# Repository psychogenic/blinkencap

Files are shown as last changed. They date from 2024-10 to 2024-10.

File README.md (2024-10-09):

# blinkencap

Blinkencap SAO for hackaday supercon badges

This is a simple badge add-on that uses the massive overkill of an ASIC to blink LEDs.

It was inspired by Matt's famous hat:
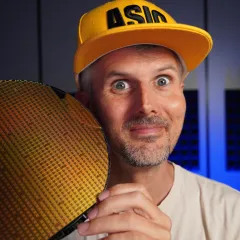
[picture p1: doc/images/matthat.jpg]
Matt and hat


so it looks like

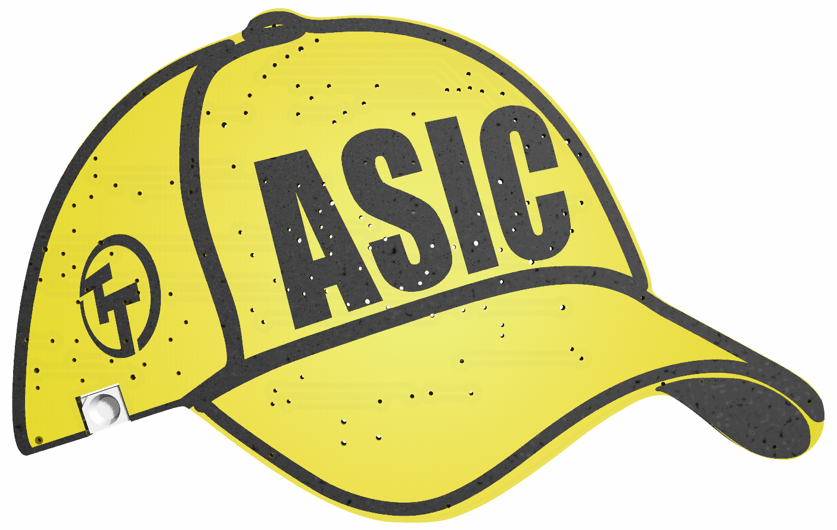
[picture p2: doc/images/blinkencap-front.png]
board front


and gives you a few interesting ways to blink a LED.  All the circuitry is hidden in the back
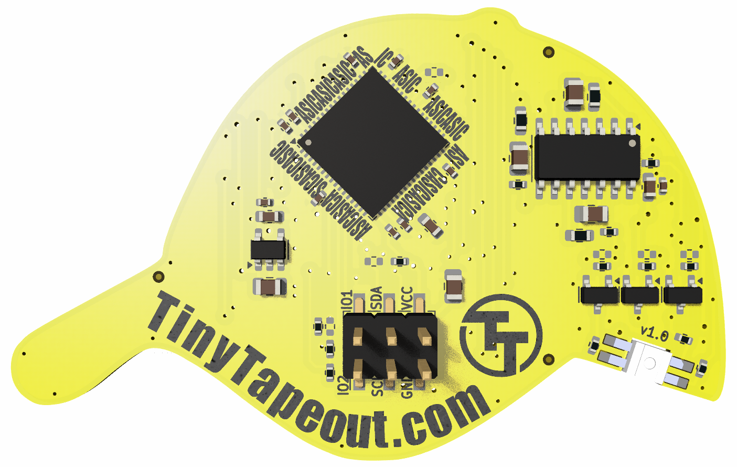
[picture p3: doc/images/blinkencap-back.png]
board components


It is my entry to the [supercon 8 add-on contest](https://hackaday.io/contest/197237-supercon-8-add-on-contest).

It has a project page on [hackaday.io](https://hackaday.io/project/198371-blinkencap), and the circuit can be opened in KiCad or [found in the docs here](https://raw.githubusercontent.com/psychogenic/blinkencap/main/doc/blinkencap-schematic.pdf), but the preview is

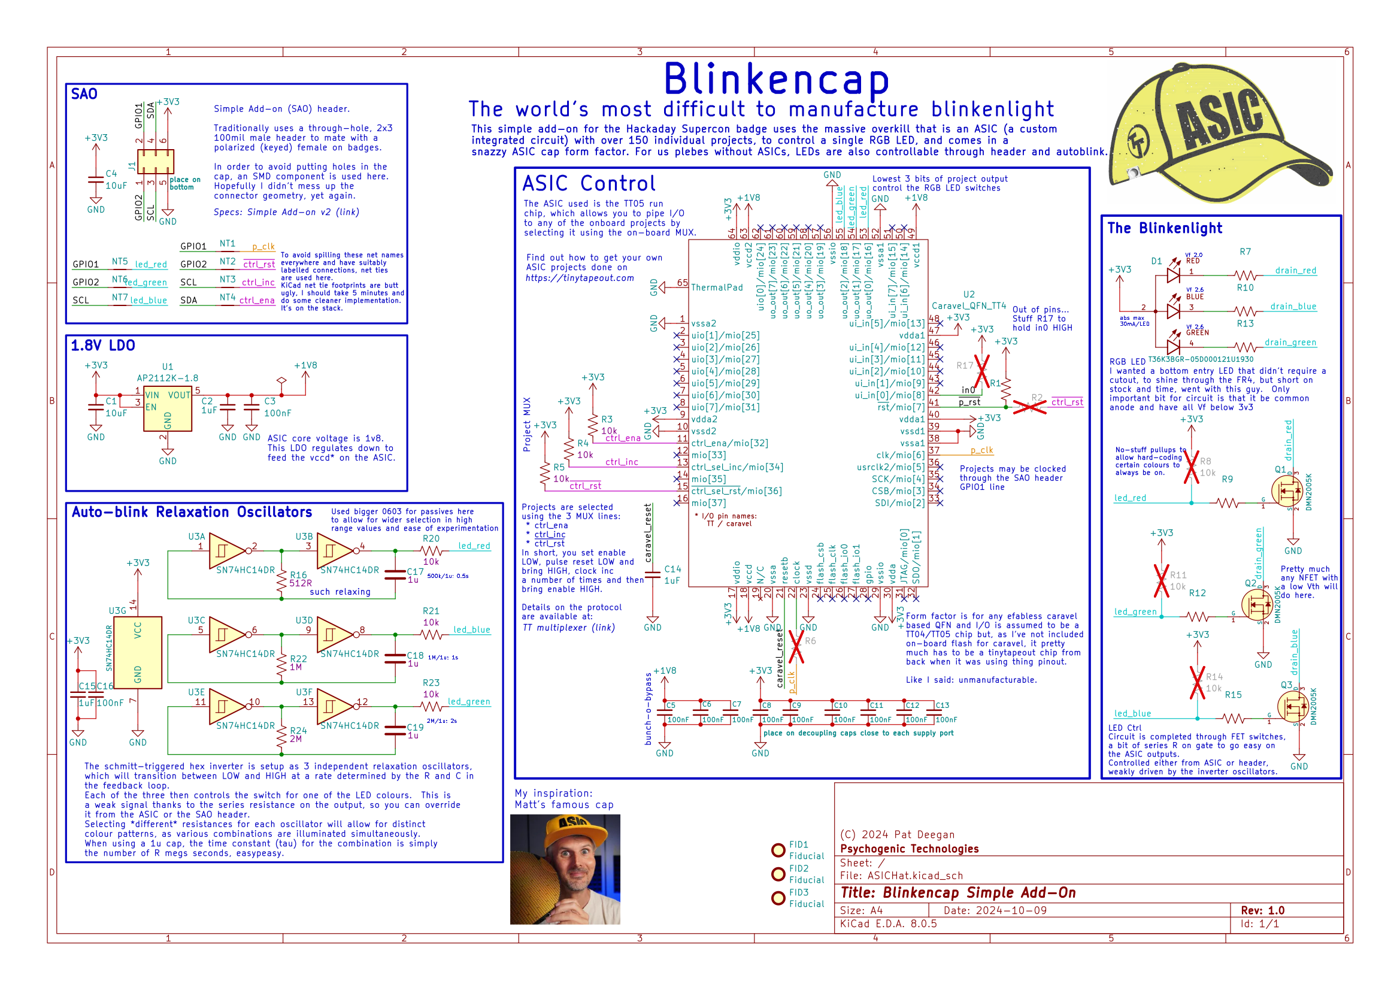
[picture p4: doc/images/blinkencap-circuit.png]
schematic
.

This project is

Copyright (C) 2024 Pat Deegan, [psychogenic.com](https://psychogenic.com)

and released under the [CERN-OHL-S](https://cern-ohl.web.cern.ch/home) open hardware license.

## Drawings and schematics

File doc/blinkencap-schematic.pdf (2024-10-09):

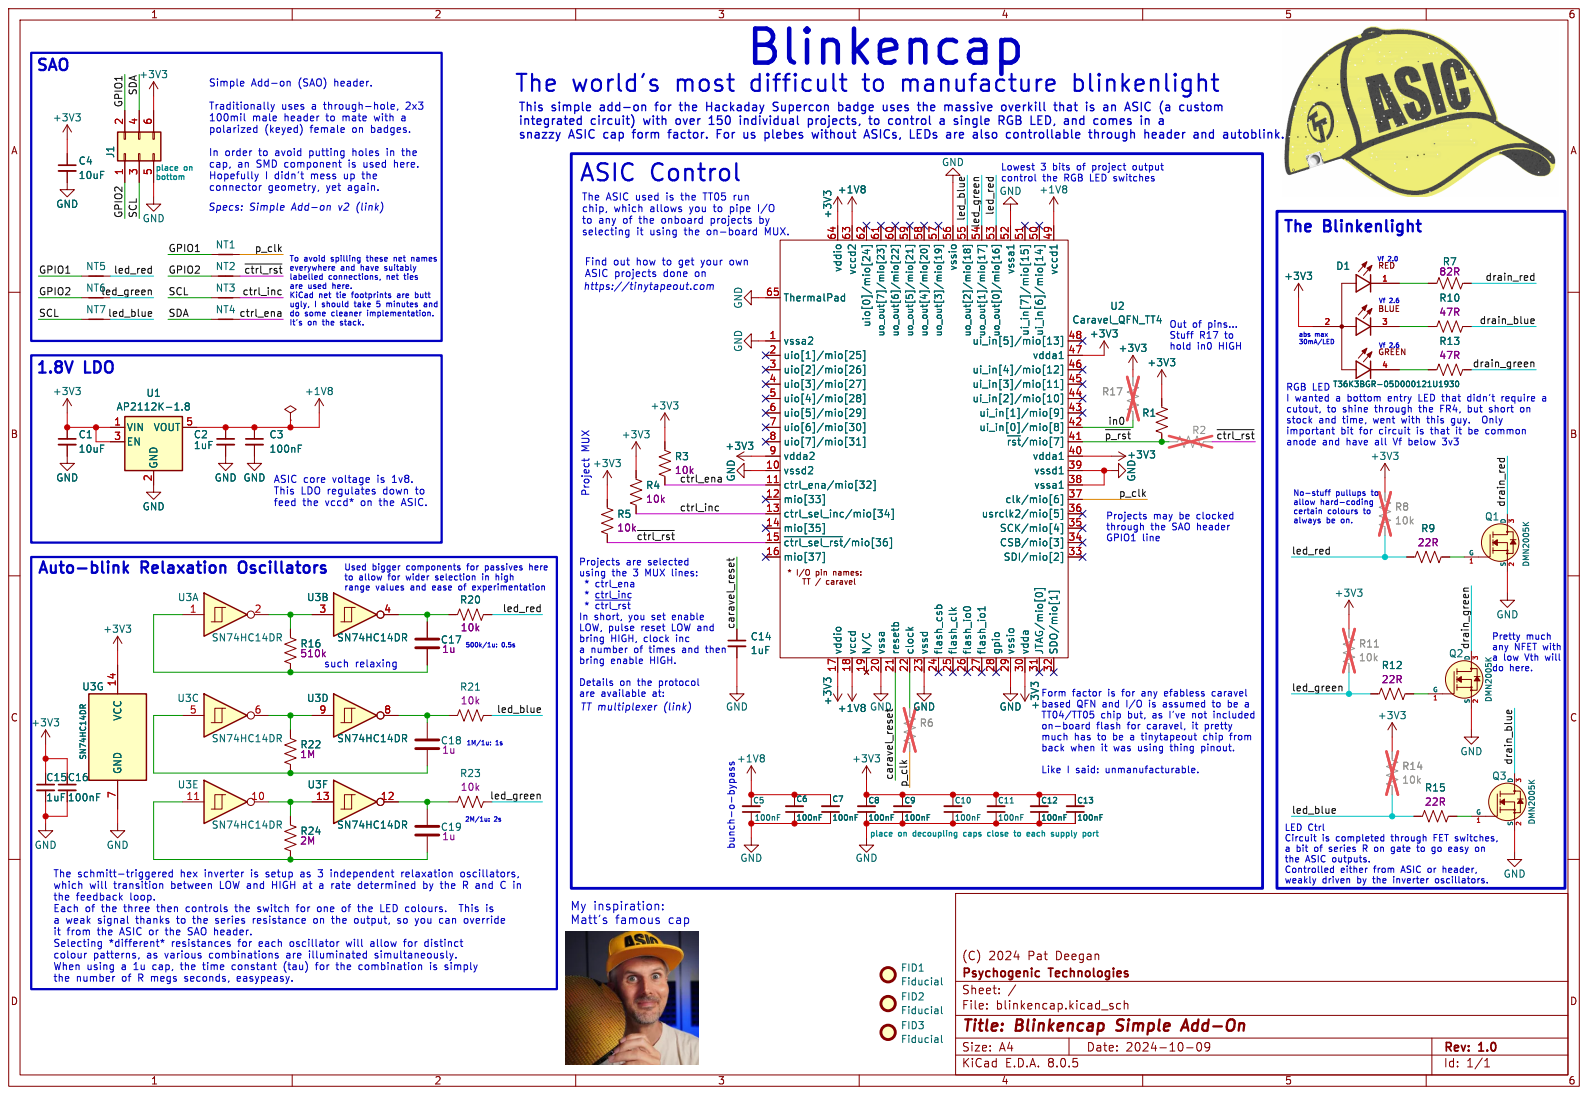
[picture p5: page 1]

always be on. place on decoupling caps close to each supply port Blinkencap Project MUX

The ASIC used is the TT05 run
chip, which allows you to pipe I/O

It's on the stack. 1.8V LDO

Out of pins... Stuff R17 to

I wanted a bottom entry LED that didn't require a
cutout, to shine through the FR4, but short on

through the SAO header GPIO1 line

range values and ease of experimentation

using the 3 MUX lines: * ctrl_ena

* ctrl_inc
* ~{ctrl_rst}
In short, you set enable
LOW, pulse reset LOW and
bring HIGH, clock inc a number of times and then

Id: 1/1 Title: Blinkencap Simple Add-On

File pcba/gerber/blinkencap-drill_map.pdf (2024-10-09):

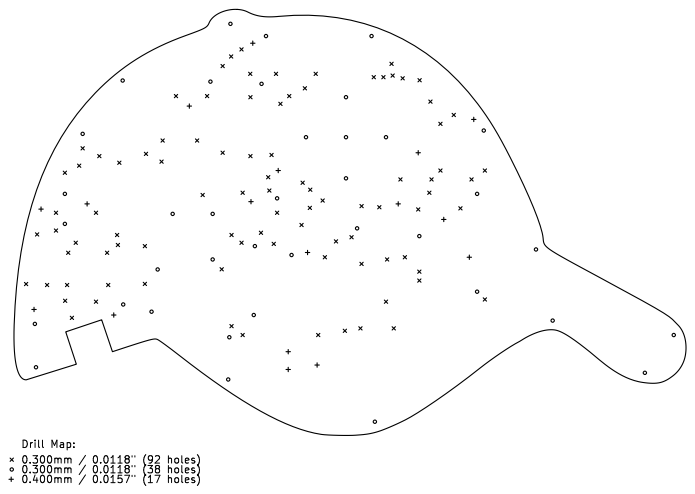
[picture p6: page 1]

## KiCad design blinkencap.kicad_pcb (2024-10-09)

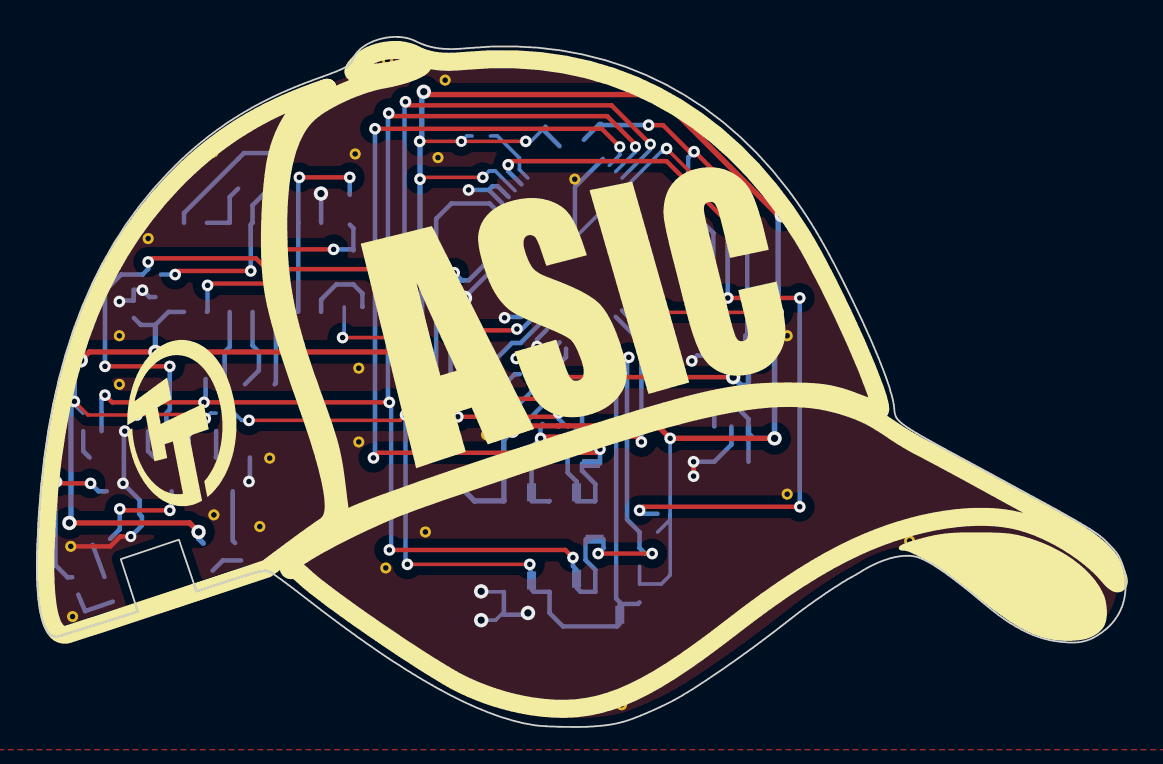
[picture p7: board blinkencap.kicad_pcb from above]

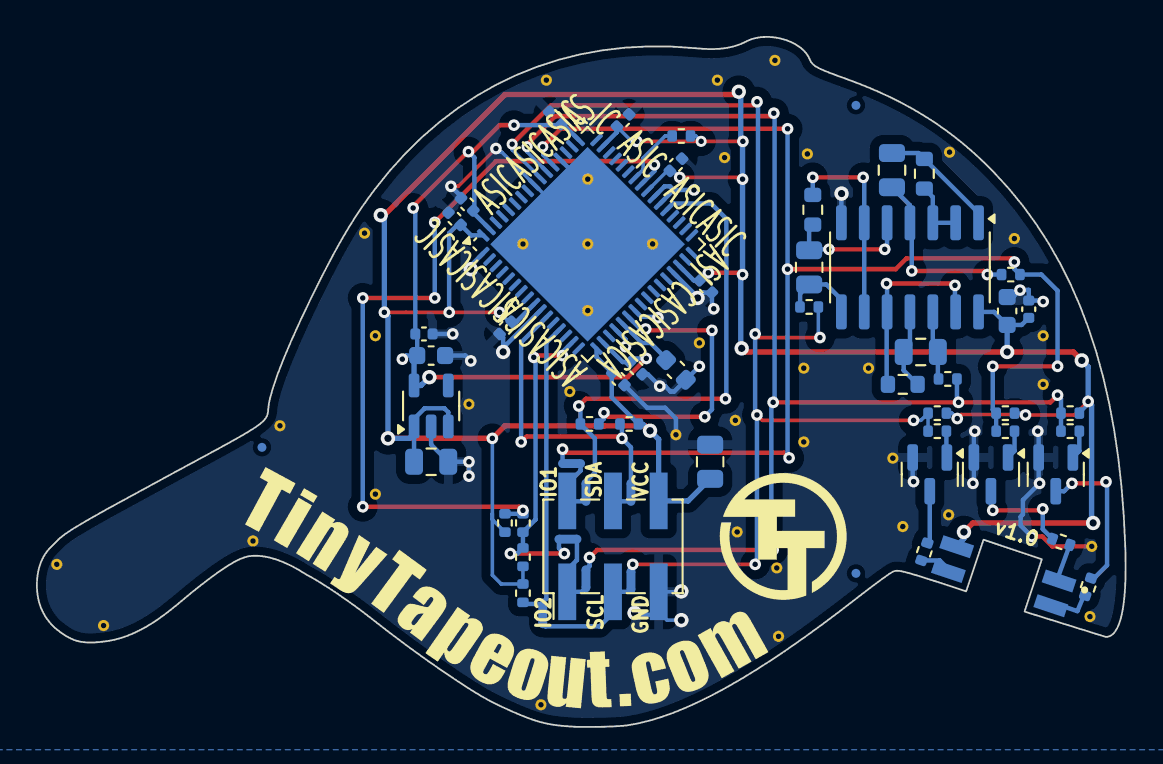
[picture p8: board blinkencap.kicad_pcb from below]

Board: 2 copper layers, 60.5 x 38.3 mm, 100 parts (60 on the bottom side), 36 nets.

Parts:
ASICCAP_SILK: asic_capsilk_2
C1, C4: 10uF; C_0805_2012Metric
C2, C14, C15: 1uF; C_0603_1608Metric
C3, C5, C6, C7, C8, C9, C10, C11, C12, C13, C16: 100nF; C_0402_1005Metric
C17, C18, C19: C_470n_0603_50V; C_0805_2012Metric
CAPOUTLINE*: CAPOUTLINE; asic_capoutline_cutout
D1: T36K3BGR-05D000121U1930; LED_T36K3BGR-05D000121U1930
FID1, FID2, FID3: Fiducial; Fiducial_0.5mm_Mask1mm
J1: Conn_02x03_Odd_Even; PinHeader_2x03_P2.54mm_Vertical_SMD
NT1, NT2, NT3, NT4, NT5, NT6, NT7: NetTie_2; NetTie-2_SMD_Pad0.5mm
Q1, Q2, Q3: DMN2005K; SOT-23
R1, R2, R6, R17: R_0R_0402; R_0402_1005Metric
R3, R4, R5, R8, R11, R14: R_10k_0402; R_0402_1005Metric
R7, R10, R13: R_412_0402; R_0402_1005Metric
R9, R12, R15: R_22R_0402; R_0402_1005Metric
R16, R22, R24: R_1M_0603; R_0603_1608Metric
R20, R21, R23: R_1k_0402; R_0402_1005Metric
STITCH1, STITCH1#2, STITCH1#3, STITCH1#4, STITCH1#5, STITCH1#6, STITCH2, STITCH3, STITCH4, STITCH5, STITCH6, STITCH7, STITCH8, STITCH9, STITCH10, STITCH10#2, STITCH11, STITCH12, STITCH12#2, STITCH12#3, STITCH13, STITCH13#2, STITCH14, STITCH15, STITCH16, STITCH17, STITCH18, STITCH19, STITCH20, STITCH21, STITCH21#2, STITCH21#3, STITCH21#4, STITCH21#5, STITCH22, STITCH23, STITCH24, STITCH25: StitchingVia-0.3mm
TTCurvyText: asichat_tttext
U1: AP2112K-1.8; SOT-23-5
U2: Caravel_QFN_TT4; QFN-64-1EP_9x9mm_P0.5mm_EP7.65x7.65mm
U3: SN74HC14DR; SOIC-14_3.9x8.7mm_P1.27mm

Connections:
+1V8: C2.1, C3.1, C5.2, C6.2, C7.2, U1.5 (VOUT), U2.18 (vccd), U2.49 (vccd1), U2.63 (vccd2)
+3V3: C1.1, C4.1, C8.2, C9.2, C10.2, C11.2, C12.2, C13.2, C15.1, C16.1, D1.2, J1.6, R1.1, R3.1, R4.1, R5.1, R8.1, R11.1, R14.1, R17.2, U1.1 (VIN), U1.3 (EN), U2.9 (vdda2), U2.17 (vddio), U2.30 (vdda), U2.40 (vdda1), U2.47 (vdda1), U2.64 (vddio), U3.14 (VCC)
/GPIO1: J1.2, NT1.1, NT5.1
/GPIO2: J1.1, NT2.1, NT6.1
/SCL: J1.3, NT3.1, NT7.1
/SDA: J1.4, NT4.1
/caravel_reset: C14.1, U2.21 (resetb)
/ctrl_ena: NT4.2, R3.2, U2.11 (ctrl_ena/mio[32])
/ctrl_inc: NT3.2, R4.2, U2.13 (ctrl_sel_inc/mio[34])
/drain_blue: Q3.3 (D), R10.2
/drain_green: Q2.3 (D), R13.2
/drain_red: Q1.3 (D), R7.2
/in0: R17.1, U2.42 (ui_in[0]/mio[8])
/led_blue: NT7.2, R14.2, R15.1, R21.2, U2.55 (uo_out[2]/mio[18])
/led_green: NT6.2, R11.2, R12.1, R23.2, U2.54 (uo_out[1]/mio[17])
/led_red: NT5.2, R8.2, R9.1, R20.2, U2.53 (uo_out[0]/mio[16])
/p_clk: NT1.2, R6.1, U2.37 (clk/mio[6])
/~ctrl_rst: NT2.2, R2.2, R5.2, U2.15 (~ctrl_sel_rst/mio[36])
/~p_rst: R1.2, R2.1, U2.41 (~rst/mio[7])
GND: C1.2, C2.2, C3.2, C4.2, C5.1, C6.1, C7.1, C8.1, C9.1, C10.1, C11.1, C12.1, C13.1, C14.2, C15.2, C16.2, J1.5, Q1.2 (S), Q2.2 (S), Q3.2 (S), STITCH1.1, STITCH1#2.1, STITCH1#3.1, STITCH1#4.1, STITCH1#5.1, STITCH1#6.1, STITCH2.1, STITCH3.1, STITCH4.1, STITCH5.1, STITCH6.1, STITCH7.1, STITCH8.1, STITCH9.1, STITCH10.1, STITCH10#2.1, STITCH11.1, STITCH12.1, STITCH12#2.1, STITCH12#3.1, STITCH13.1, STITCH13#2.1, STITCH14.1, STITCH15.1, STITCH16.1, STITCH17.1, STITCH18.1, STITCH19.1, STITCH20.1, STITCH21.1, STITCH21#2.1, STITCH21#3.1, STITCH21#4.1, STITCH21#5.1, STITCH22.1, STITCH23.1, STITCH24.1, STITCH25.1, U1.2 (GND), U2.1 (vssa2), U2.10 (vssd2), U2.20 (vssa), U2.23 (vssd), U2.29 (vssio), U2.38 (vssa1), U2.39 (vssd1), U2.52 (vssa1), U2.56 (vssio), U2.65 (ThermalPad), U3.7 (GND)
unnamed: C17.1, R20.1, U3.4
unnamed: C17.2, R16.2, U3.1
unnamed: C18.1, R21.1, U3.8
unnamed: C18.2, R22.2, U3.5
unnamed: C19.1, R23.1, U3.12
unnamed: C19.2, R24.2, U3.11
unnamed: D1.1, R7.1
unnamed: D1.3, R10.1
unnamed: D1.4, R13.1
unnamed: Q1.1 (G), R9.2
unnamed: Q2.1 (G), R12.2
unnamed: Q3.1 (G), R15.2
unnamed: R16.1, U3.2, U3.3
unnamed: R22.1, U3.6, U3.9
unnamed: R24.1, U3.10, U3.13
unnamed: R6.2, U2.22 (clock)

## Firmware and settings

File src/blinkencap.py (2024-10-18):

'''
Created on Oct 18, 2024

Basic uPython driver for the blinkencap

@author: Pat Deegan
@copyright: Copyright (C) 2024 Pat Deegan, https://psychogenic.com
'''
import machine 
import time
PIDX_NRST = 19
PIDX_CLK = 20
PIDX_INC = 21
PIDX_ENA = 22

_BlinkenDriver_Singleton = None 
class BlinkenDriver:
    def __init__(self):
        self.pin_nrst = machine.Pin(PIDX_NRST, machine.Pin.OUT)
        self.pin_clk = machine.Pin(PIDX_CLK, machine.Pin.OUT)
        self.pin_ena = machine.Pin(PIDX_ENA, machine.Pin.OUT)
        self.pin_inc = machine.Pin(PIDX_INC, machine.Pin.OUT)
        
        for p in [self.pin_nrst, self.pin_clk, self.pin_ena, self.pin_inc]:
            p.value(0)

    def select_project(self, idx:int):
        print(f"selecting project {idx}")
        self.pin_nrst.value(0)
        self.pin_ena.value(0)
        self.pin_inc.value(0)
        time.sleep_ms(2)
        
        self.pin_nrst.value(1)
        time.sleep_ms(2)
        
        # send the number of pulses required
        for _c in range(idx):
            self.pin_inc.value(1)
            time.sleep_ms(1)
            self.pin_inc.value(0)
            time.sleep_ms(1)
            
        self.pin_ena.value(1)
    
    def clock_once(self):
        self.pin_clk.value(0)
        time.sleep_ms(1)
        self.pin_clk.value(1)
        time.sleep_ms(1)
        self.pin_clk.value(0)
        
def getDriver():
    global _BlinkenDriver_Singleton
    if _BlinkenDriver_Singleton is None:
        _BlinkenDriver_Singleton = BlinkenDriver()
    
    return _BlinkenDriver_Singleton 


def run(proj_idx:int=1, num_clocks:int=30, delayms:int=500):
    drv = getDriver()
    drv.select_project(proj_idx)
    for _c in range(num_clocks):
        drv.clock_once()
        time.sleep_ms(delayms)
        
        
    
    
    

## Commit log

2024-10-09 preliminary commit
    [blinkencap-B_Courtyard.gbr, blinkencap-B_Cu.gbr, blinkencap-B_Fab.gbr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]
2024-10-18 uPython driver for ASIC populated caps
